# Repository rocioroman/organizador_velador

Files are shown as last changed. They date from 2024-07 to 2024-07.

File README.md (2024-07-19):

# Organizador para velador

Este diseño surge a partir de la necesidad de organizar el espacio utilizado por los objetos que se colocan sobre un velador y mejorar la estabilidad de la lámpara ubicada en este. Cuenta con estantes para colocar libros, una bandeja central para items de uso diario (como reloj, billetera y collares) y una apertura para acople con lámpara.
Los archivos de diseño se encuentran en la carpeta **/archivos/diseño**.

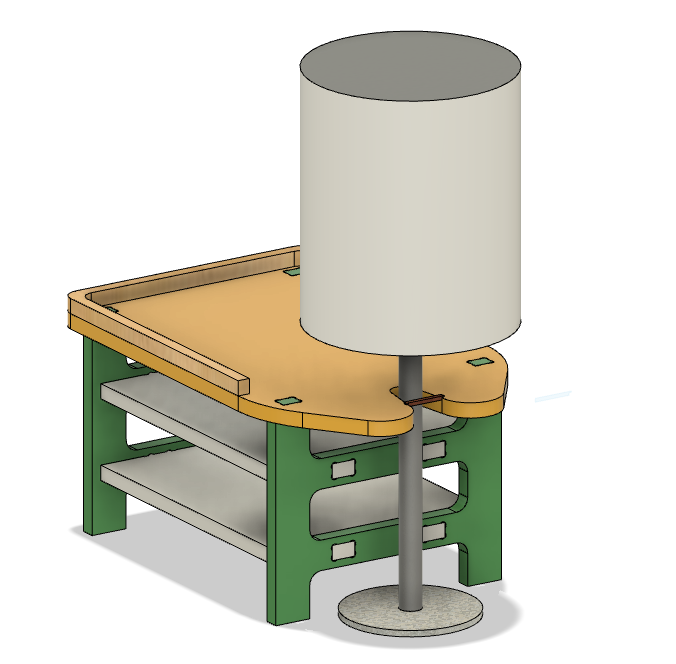
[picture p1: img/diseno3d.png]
Diseño 3d
 

## Lista de materiales 
- Pliego de madera terciada 12mm de dimensiones 65cm x 51cm
- 1gr de filamento PLA para impresión 3D
- Pegamento de madera
- Almohadilla fieltro
- Palos pequeños de madera ("palitos de helado", o "palitos para manualidades")

El costo aproximado del proyecto este de 7000 pesos, considerando 1/4 de "pliego" de madera, el fieltro y los palillos de madera.
## Fabricación Partes y Ensamble
### Partes
El proyecto consta de 5 piezas principales: 

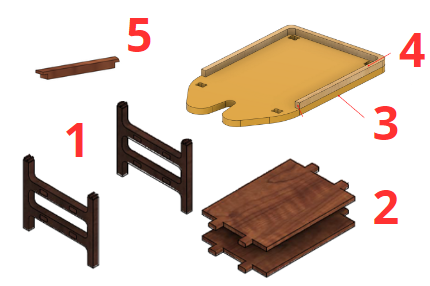
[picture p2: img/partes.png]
Partes diseño
 

| # | Pieza | Material | Fabricación  |
|---|---|---|---|
| 1 | Paredes x2 | Madera | Corte CNC |
| 2 | Estante x2 | Madera | Corte CNC |
| 3 | Base Bandeja  | Madera | Corte CNC |
| 4 | Borde Bandeja | Madera | Corte CNC |
| 5 | Soporte Lámpara  | PLA | Impresión 3D |

### Fabricación 
**Corte CNC**
1. Realizar el corte de las piezas de madera acorde al archivo de diseño *corteCNC.f3d* presente en la carpeta **/archivos/construcción**. El diseño está hecho para utilizar una fresa con diámetro máximo de 6mm. El archivo *corteCNC.sbp* presente en la misma carpeta cuenta con las instrucciones de corte utilizando una fresa punta plana Ø1/8" que cuenta con pestañas o *tabs* para evitar el movimiento de piezas durante el proceso de corte.
2. Remueva las pestañas y lije la pieza para eliminar cualquier irregularidad.

**Impresión 3D**
1. Imprima el soporte/ tope de la lámpara utilizando el archivo *impresion3D.stl* presente en la carpeta **/archivos/construcción**.

## Ensamble
1. Pegar la pieza 3 y 4 con pegamento de madera para formar la bandeja, asegurándose que sus bordes se alineen. Dejar prensado por lo menos por un día para garantizar un buen pegado.
2. Unir las paredes (1) con los estantes (2). Las paredes van de forma vertical y los estantes de forma horizontal. Debe quedar un tipo de mesa con dos estantes.
3. Corte 2 pedazos de 12mm de largo de los palos de madera pequeños. Péguelos en la apertura de la bandeja con el pegamento de madera para obtener un tope del soporte como se ve en la siguiente figura.



4. Unir en la parte superior de la estructura la bandeja, haciendo calzar sus agujeros con la espiga de las paredes.
5. Cubra la base de las paredes con fieltro para asegurar no rayar el velador. Cortar para adecuar al tamaño.



6. Al momento de unir la lámpara a la bandeja, coloque el tope impreso de la lámpara para evitar la caída de esta.

### Imagenes ensamblado listo

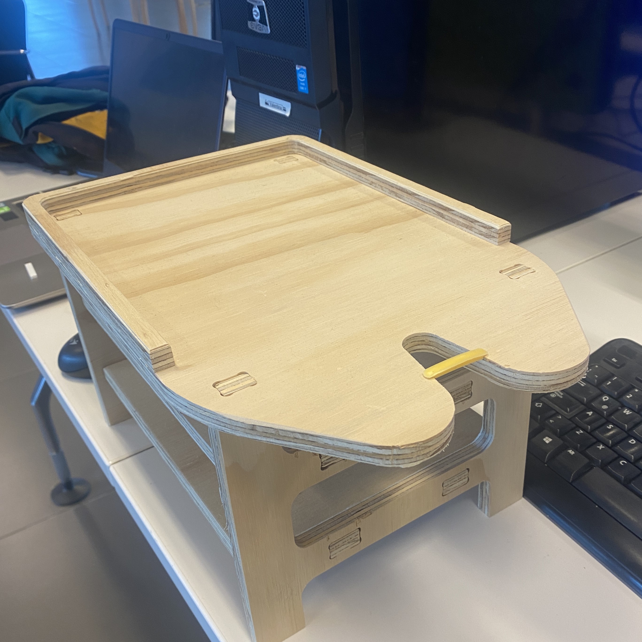
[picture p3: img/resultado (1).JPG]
 
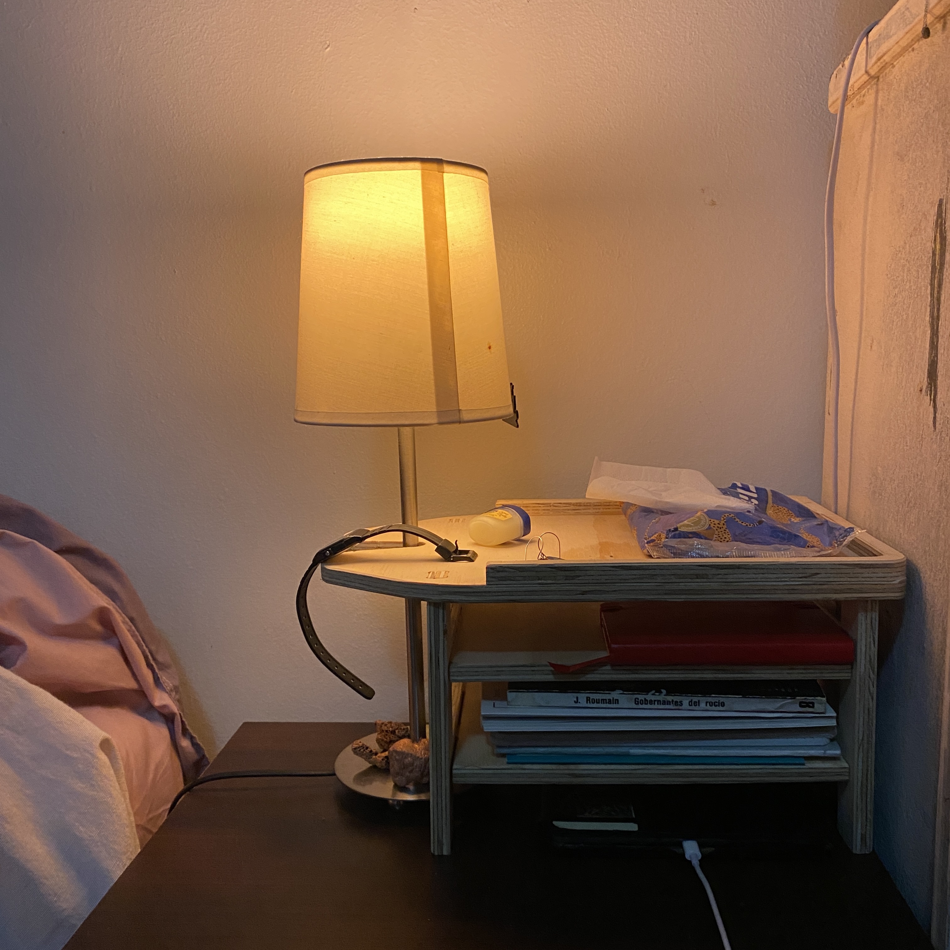
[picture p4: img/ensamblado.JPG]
 

## Posible mejoras

- Integrar el tope para el soporte de la lámpara al diseño
- Modificar entrada lámpara para no requerir del tope impreso
- Integrar una lámpara propia al diseño

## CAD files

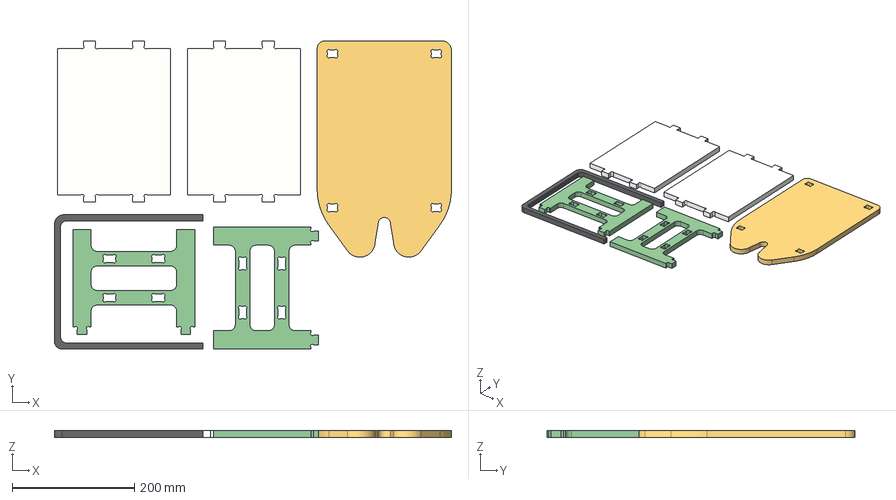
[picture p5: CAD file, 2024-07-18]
archivos/construcción/corteCNC.step
650.0 x 504.5 x 12.0 mm
Paredes
Estantes
Plato

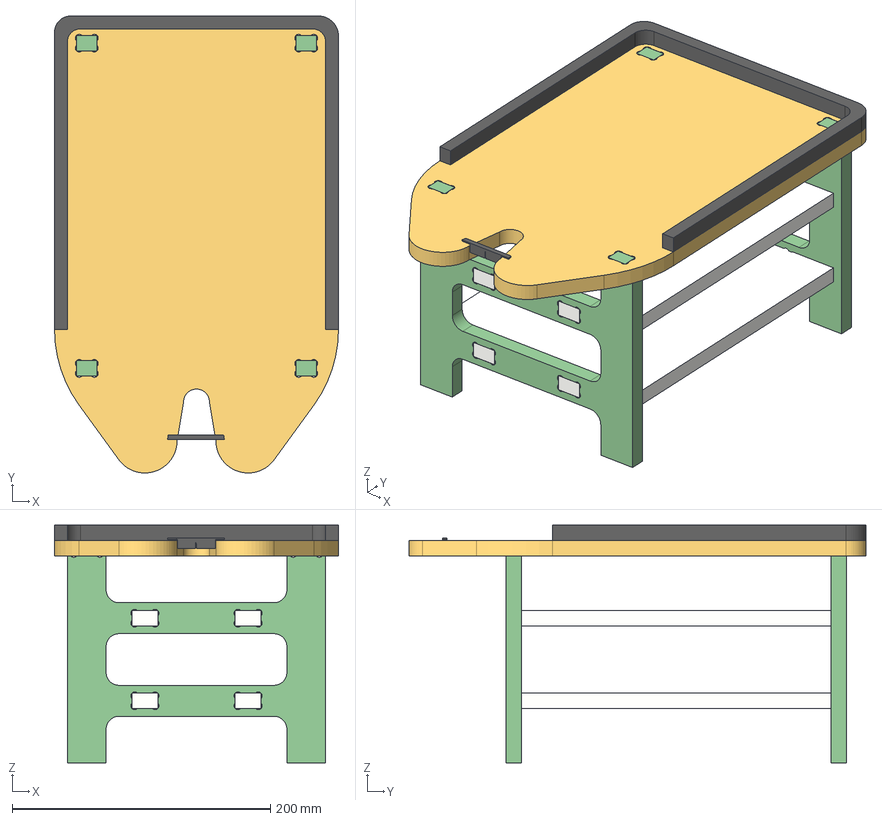
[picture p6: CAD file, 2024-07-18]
archivos/diseño/diseno_3D.step
220.0 x 354.0 x 184.0 mm
Paredes
Estantes
Plato
soporte

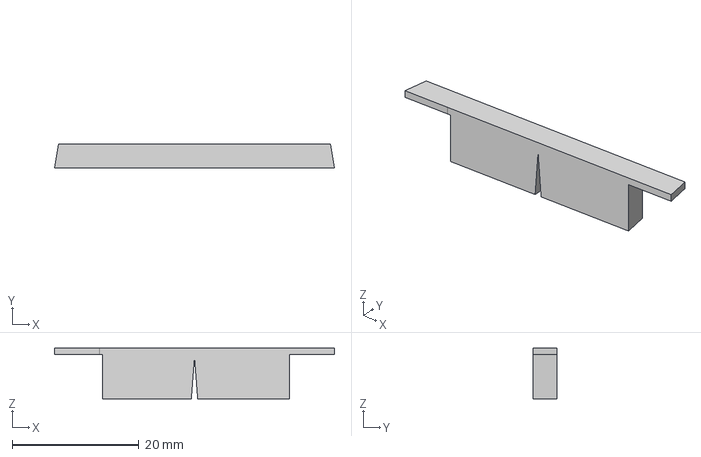
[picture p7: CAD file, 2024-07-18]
archivos/construcción/soporte.step
44.1 x 3.72 x 8.00 mm

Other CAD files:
archivos/construcción/impresion3D.stl
archivos/construcción/corteCNC.f3d
archivos/construcción/soporte.f3d
archivos/diseño/Diseno_3D.f3d
